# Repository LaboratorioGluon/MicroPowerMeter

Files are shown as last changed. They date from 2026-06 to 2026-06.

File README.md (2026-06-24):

# MicroPowerMeter

This repo contains the Hardware design of my version of a low current meter (from nanoamperes to milliamperes).

More Info [Blog Entry](https://en.laboratoriogluon.com/projects/micropowermeter/).

## Capabilities

- 4 kSps
- 3 Ranges: nA, uA and mA.
- Automatic range switching
- USB connection.
- Low Burden Voltage:
    - 10 uV/nA 
    - 10 uV/uA
    - 10 uV/mA

## Electrical characteristics

- TBD

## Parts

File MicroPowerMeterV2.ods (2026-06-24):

Reference | Qty | Value | PiceUd | Total price | DNP | Exclude from BOM | Footprint | Datasheet
C1,C3,C5,C6,C11,C23,C24,C50,C51,C53,C56 | 11 | 1u | 0.0022 | 0.0242 |  |  | Capacitor_SMD:C_0603_1608Metric
C2,C4,C52 | 3 | 100u | 0.06 | 0.18 |  |  | Capacitor_SMD:C_0603_1608Metric
C7,C42,C48 | 3 | 100n | 0.0022 | 0.0066 |  |  | Capacitor_SMD:C_0603_1608Metric_Pad1.08x0.95mm_HandSolder
C8 | 1 | 4u7 | 0.0022 | 0.0022 |  |  | Capacitor_SMD:C_0603_1608Metric_Pad1.08x0.95mm_HandSolder
C9,C10 | 2 | 10n | 0.0022 | 0.0044 |  |  | Capacitor_SMD:C_0603_1608Metric_Pad1.08x0.95mm_HandSolder
C12,C13,C47,C49 | 4 | 1uF | 0.0022 | 0.0088 |  |  | Capacitor_SMD:C_0603_1608Metric_Pad1.08x0.95mm_HandSolder
C14 | 1 | 220n | 0.0022 | 0.0022 |  |  | Capacitor_SMD:C_0603_1608Metric_Pad1.08x0.95mm_HandSolder
C15,C16,C19,C20,C25,C29,C30,C31,C34,C36,C39,C40,C41,C43,C44,C45,C46 | 17 | 100n | 0.0022 | 0.0374 |  |  | Capacitor_SMD:C_0603_1608Metric
C17,C18,C21,C22,C57,C58,C59,C60,C61,C62 | 10 | 22n | 0.0022 | 0.022 |  |  | Capacitor_SMD:C_0603_1608Metric
C26,C27 | 2 | 220n | 0.0022 | 0.0044 |  |  | Capacitor_SMD:C_0603_1608Metric
C28,C37,C38 | 3 | 100u | 0.06 | 0.18 |  |  | Capacitor_SMD:CP_Elec_6.3x5.4
C32,C33 | 2 | 10u | 0.0022 | 0.0044 |  |  | Capacitor_SMD:C_0603_1608Metric
C35 | 1 | 4u7 | 0.0022 | 0.0022 |  |  | Capacitor_SMD:C_0603_1608Metric
D1 | 1 | V_USB | 0.004 | 0.004 |  |  | LED_SMD:LED_0603_1608Metric
D2,D3 | 2 | V_3v3 | 0.004 | 0.008 |  |  | LED_SMD:LED_0603_1608Metric
D4 | 1 | 1N5819WS |  | 0 |  |  | Diode_SMD:D_SOD-323_HandSoldering | https://datasheet.lcsc.com/lcsc/2204281430_Guangdong-Hottech-1N5819WS_C191023.pdf
D5 | 1 | BAT54C | 0.02 | 0.02 |  |  | Package_TO_SOT_SMD:SOT-23 | http://www.diodes.com/_files/datasheets/ds11005.pdf
FB1,FB2 | 2 | 300R | 0.02 | 0.04 |  |  | Inductor_SMD:L_0603_1608Metric
J1 | 1 | USB_C_Receptacle_USB2.0_16P | 0.034 | 0.034 |  |  | USB_C_Receptacle_GCT_USB4105-xx-A_16P_TopMnt_Horizontal | https://www.usb.org/sites/default/files/documents/usb_type-c.zip
J2 | 1 | UART_DBG_CT |  | 0 |  |  | Connector_PinHeader_2.54mm:PinHeader_1x04_P2.54mm_Vertical
J3,J5 | 2 | SWD |  | 0 |  |  | Connector_PinHeader_2.54mm:PinHeader_1x04_P2.54mm_Vertical
J4 | 1 | OLED |  | 0 |  |  | GluonLib:OLED_0.96_footprint
J6 | 1 | BANANA_VIN | 0.5 | 0.5 |  |  | Connector_Wire:SolderWirePad_1x01_SMD_4x8mm
J7 | 1 | BANANA_DUT_P | 0.5 | 0.5 |  |  | Connector_Wire:SolderWirePad_1x01_SMD_4x8mm
J8,J9,J10,J11 | 4 | LED | 0.012 | 0.048 |  |  | Connector_PinHeader_2.54mm:PinHeader_1x02_P2.54mm_Vertical
J12 | 1 | SW | 0.05 | 0.05 |  |  | Connector_PinHeader_2.54mm:PinHeader_1x02_P2.54mm_Vertical
JP1 | 1 | 9VCurrent | 0.012 | 0.012 |  |  | Connector_PinHeader_2.54mm:PinHeader_1x02_P2.54mm_Vertical
Q1 | 1 | DMG2302UKQ | 0.149 | 0.149 |  |  | Package_TO_SOT_SMD:SOT-23
Q2 | 1 | DMG2302 | 0.149 | 0.149 |  |  | Package_TO_SOT_SMD:SOT-23
Q3,Q4 | 2 | IRLML2502 | 0.32 | 0.64 |  |  | Package_TO_SOT_SMD:SOT-23
R1,R2,R3,R4,R5,R6,R7,R15,R36 | 9 | 1k | 0.001 | 0.009 |  |  | Resistor_SMD:R_0603_1608Metric
R8,R9,R35,R39,R48,R54 | 6 | 0 | 0.001 | 0.006 |  |  | Resistor_SMD:R_0603_1608Metric
R10 | 1 | 10K 0.05% | 0.342 | 0.342 |  |  | Resistor_SMD:R_0603_1608Metric
R11,R12 | 2 | 100 | 0.001 | 0.002 |  |  | Resistor_SMD:R_0603_1608Metric
R13,R14,R37,R38,R41,R42 | 6 | 100k | 0.001 | 0.006 |  |  | Resistor_SMD:R_0603_1608Metric
R16 | 1 | 4k7 | 0.001 | 0.001 |  |  | Resistor_SMD:R_0603_1608Metric
R17 | 1 | 10R 0.05% | 0.362 | 0.362 |  |  | Resistor_SMD:R_0603_1608Metric
R18 | 1 | 0R01 0.1% | 0.609 | 0.609 |  |  | Resistor_SMD:R_Shunt_Ohmite_LVK12
R19,R20,R33,R34,R43,R44 | 6 | 270 | 0.001 | 0.006 |  |  | Resistor_SMD:R_0603_1608Metric
R21,R22,R27,R28 | 4 | 1K 0.05% | 0.342 | 1.368 |  |  | Resistor_SMD:R_0603_1608Metric
R23,R24,R29,R30 | 4 | 6K8 0.05% | 0.358 | 1.432 |  |  | Resistor_SMD:R_0603_1608Metric
R25,R26,R31,R32 | 4 | 2k2 0.05% | 0.358 | 1.432 |  |  | Resistor_SMD:R_0603_1608Metric
R40 | 1 | 200 | 0.001 | 0.001 |  |  | Resistor_SMD:R_0603_1608Metric
R45,R46 | 2 | 5k1 | 0.001 | 0.002 |  |  | Resistor_SMD:R_0603_1608Metric
R47 | 1 | 47 | 0.001 | 0.001 |  |  | Resistor_SMD:R_0603_1608Metric
R49,R50,R51,R52,R53 | 5 | 10 | 0.001 | 0.005 |  |  | Resistor_SMD:R_0603_1608Metric
TP2 | 1 | mA_TP |  | 0 |  |  | TestPoint:TestPoint_Pad_D1.0mm
TP3 | 1 | nAuA_TP |  | 0 |  |  | TestPoint:TestPoint_Pad_D1.0mm
TP4,TP5 | 2 | vsense_TP |  | 0 |  |  | TestPoint:TestPoint_Pad_D1.5mm
U1 | 1 | STM32C071RBTx | 1.58 | 1.58 |  |  | Package_QFP:LQFP-64_10x10mm_P0.5mm | https://www.st.com/resource/en/datasheet/stm32c071rb.pdf
U2,U11 | 2 | TLV773 | 0.043 | 0.086 |  |  | Package_TO_SOT_SMD:SOT-23-5 | https://www.ti.com/lit/ds/symlink/tlv773.pdf?ts=1765118738229
U3 | 1 | TEA1-0519HI | 2.86 | 2.86 |  |  | Converter_DCDC:Converter_DCDC_TRACO_TEA1-xxxxE_THT | https://www.tracopower.com/products/tea1e.pdf
U4 | 1 | ISO6742 | 1.75 | 1.75 |  |  | Package_SO:SOIC-16W_7.5x10.3mm_P1.27mm | https://www.ti.com/lit/ds/symlink/iso6742.pdf
U5 | 1 | STM32C011F4Px | 1.2 | 1.2 |  |  | Package_SO:TSSOP-20_4.4x6.5mm_P0.65mm | https://www.st.com/resource/en/datasheet/stm32c011f4.pdf
U6 | 1 | ADS131M03xPW | 2.4 | 2.4 |  |  | Package_SO:TSSOP-20_4.4x6.5mm_P0.65mm | https://www.ti.com/lit/ds/symlink/ads131m04.pdf
U7,U8,U9,U10 | 4 | MAX4239AUT | 1.5 | 6 |  |  | Package_TO_SOT_SMD:SOT-23-6 | http://datasheets.maximintegrated.com/en/ds/MAX4238-MAX4239.pdf
U12 | 1 | LM2665M6 |  | 0 |  |  | Package_TO_SOT_SMD:SOT-23-6 | https://www.ti.com/lit/ds/symlink/lm2665.pdf
U13 | 1 | OPA320DBV | 0.641 | 0.641 |  |  | Package_TO_SOT_SMD:SOT-23-5 | http://www.ti.com/lit/ds/symlink/lmv324.pdf
U14 | 1 | TPD2EUSB30A |  | 0 |  |  | Package_TO_SOT_SMD:Texas_DRT-3 | http://www.ti.com/lit/ds/symlink/tpd2eusb30a.pdf
U15 | 1 | XC6201P532PR-G | 0.321 | 0.321 |  |  | Package_TO_SOT_SMD:SOT-89-3 | https://product.torexsemi.com/system/files/series/xc6201.pdf
U16 | 1 | NCP163ASN500T1G | 0.225 | 0.225 |  |  | Package_TO_SOT_SMD:SOT-23-5 | https://www.onsemi.com/pdf/datasheet/ncp163-d.pdf
Y1 | 1 | ECS-2520MVLC-081.92-CN-TR | 1.25 | 1.25 |  |  | Oscillator:Oscillator_SMD_ECS_2520MV-xxx-xx-4Pin_2.5x2.0mm | https://www.ecsxtal.com/store/pdf/ECS-2520MV.pdf

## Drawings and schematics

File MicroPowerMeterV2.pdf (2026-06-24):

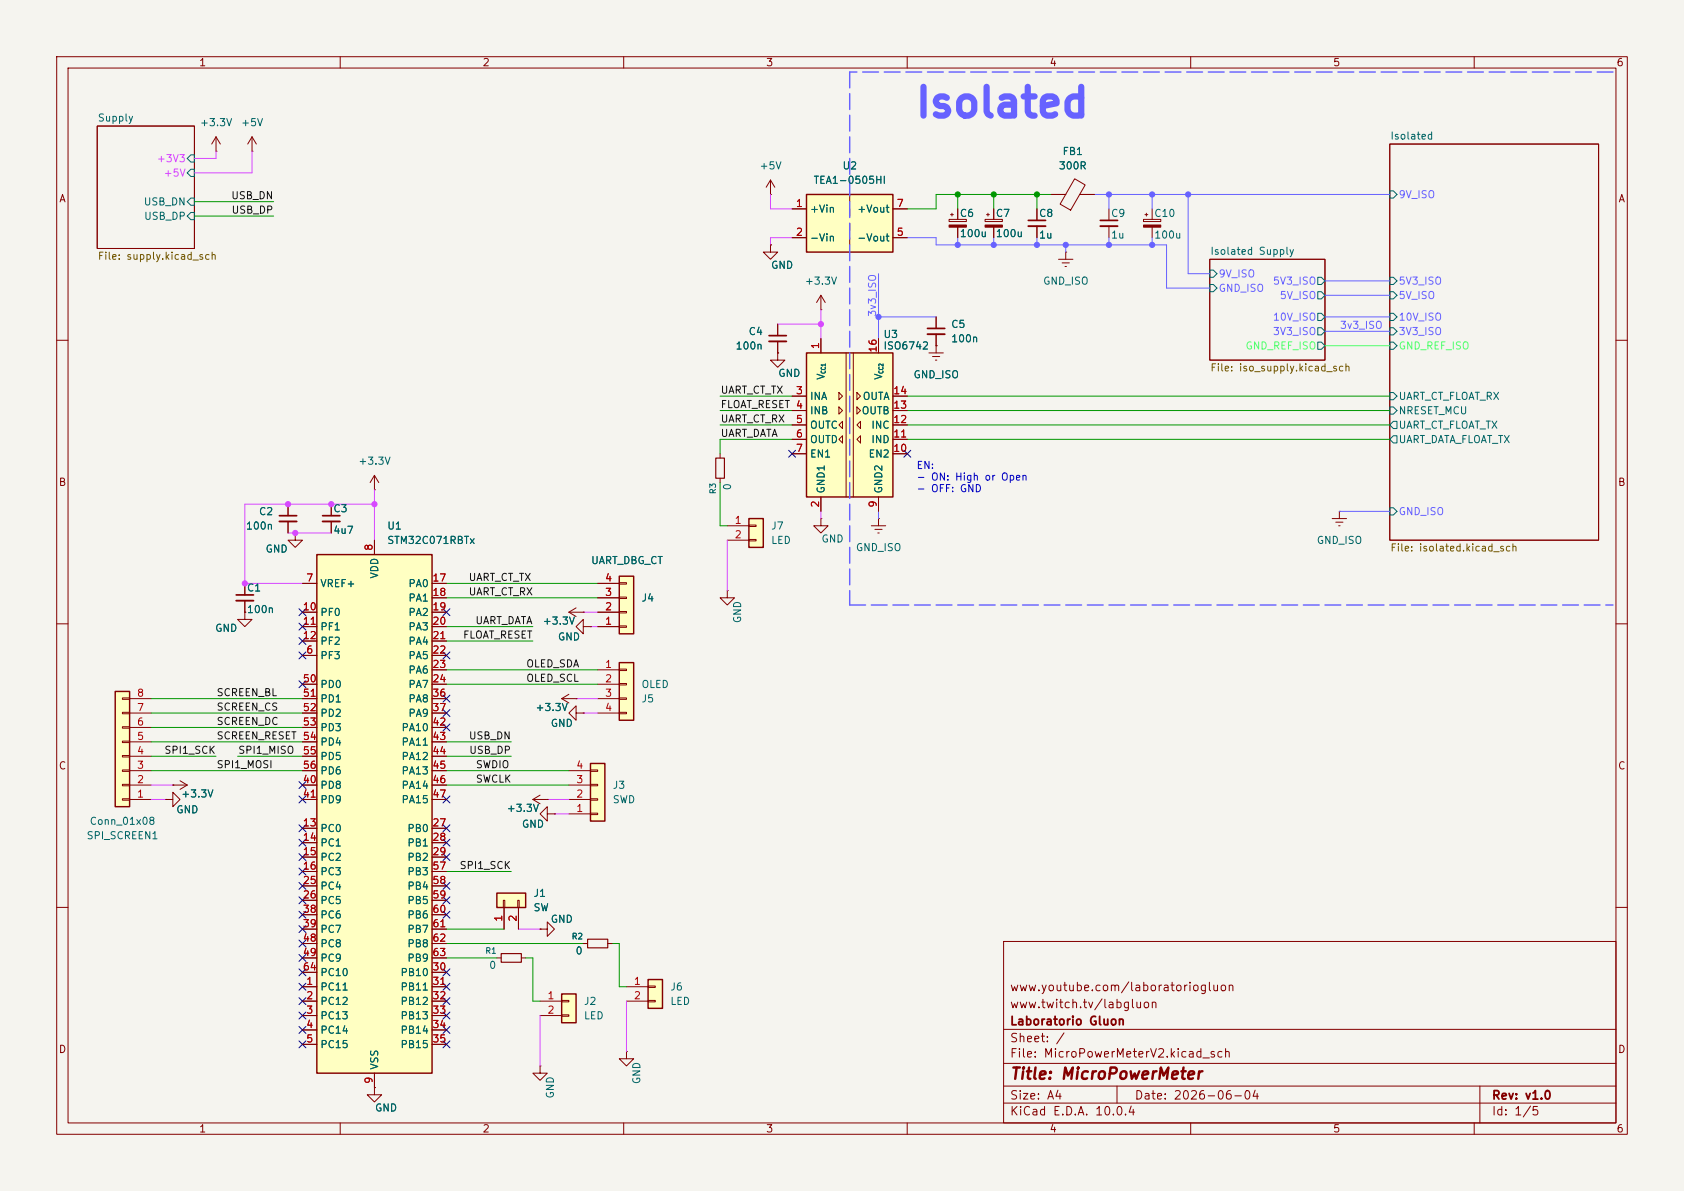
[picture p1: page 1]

EN: - ON: High or Open - OFF: GND Isolated

EN2 10 IND 11 INC 12 OUTB 13 OUTA 14

www.youtube.com/laboratoriogluon
www.twitch.tv/labgluon
Laboratorio Gluon
Sheet: /
File: MicroPowerMeterV2.kicad_sch
Title: MicroPowerMeter

Size: A4 | Rev: v1.0
KiCad E.D.A. 10.0.4 | Id: 1/5

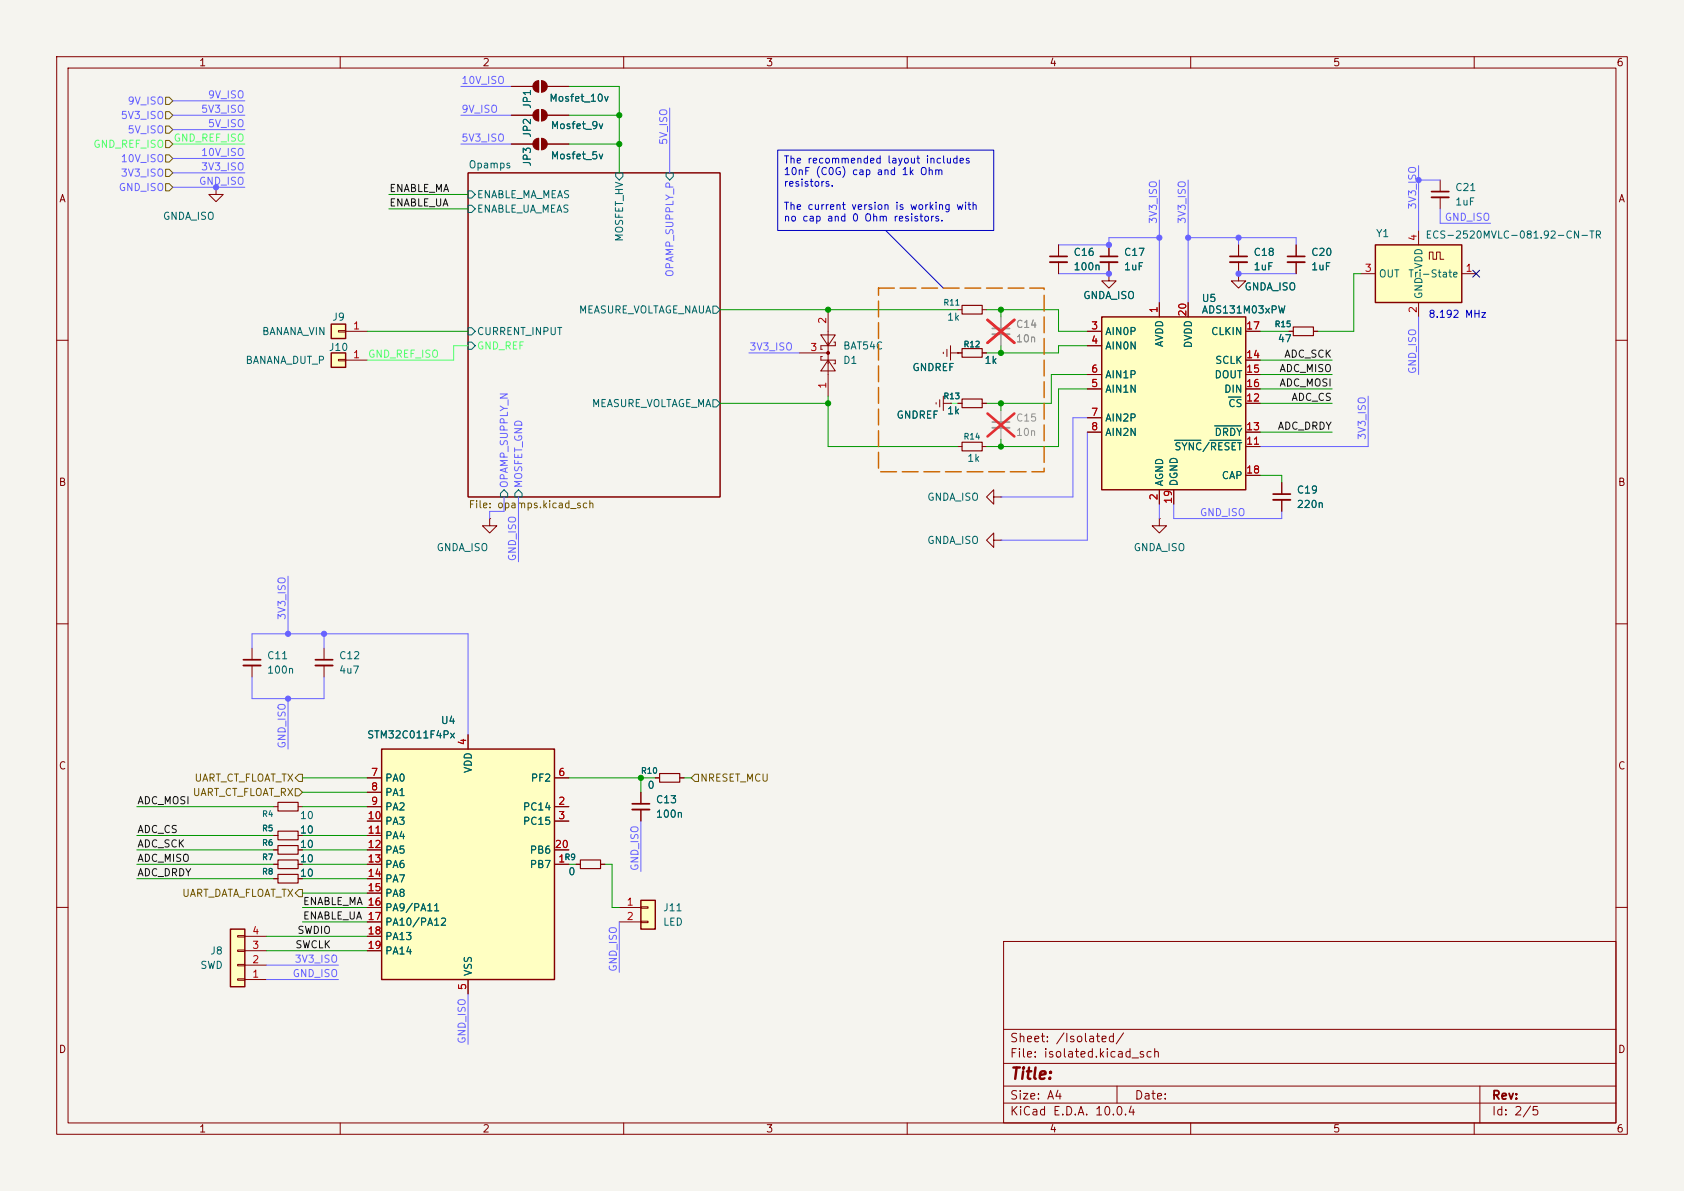
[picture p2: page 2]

The recommended layout includes 10nF (C0G) cap and 1k Ohm

resistors. The current version is working with

SYNC/RESET 11 CS 12 DRDY 13

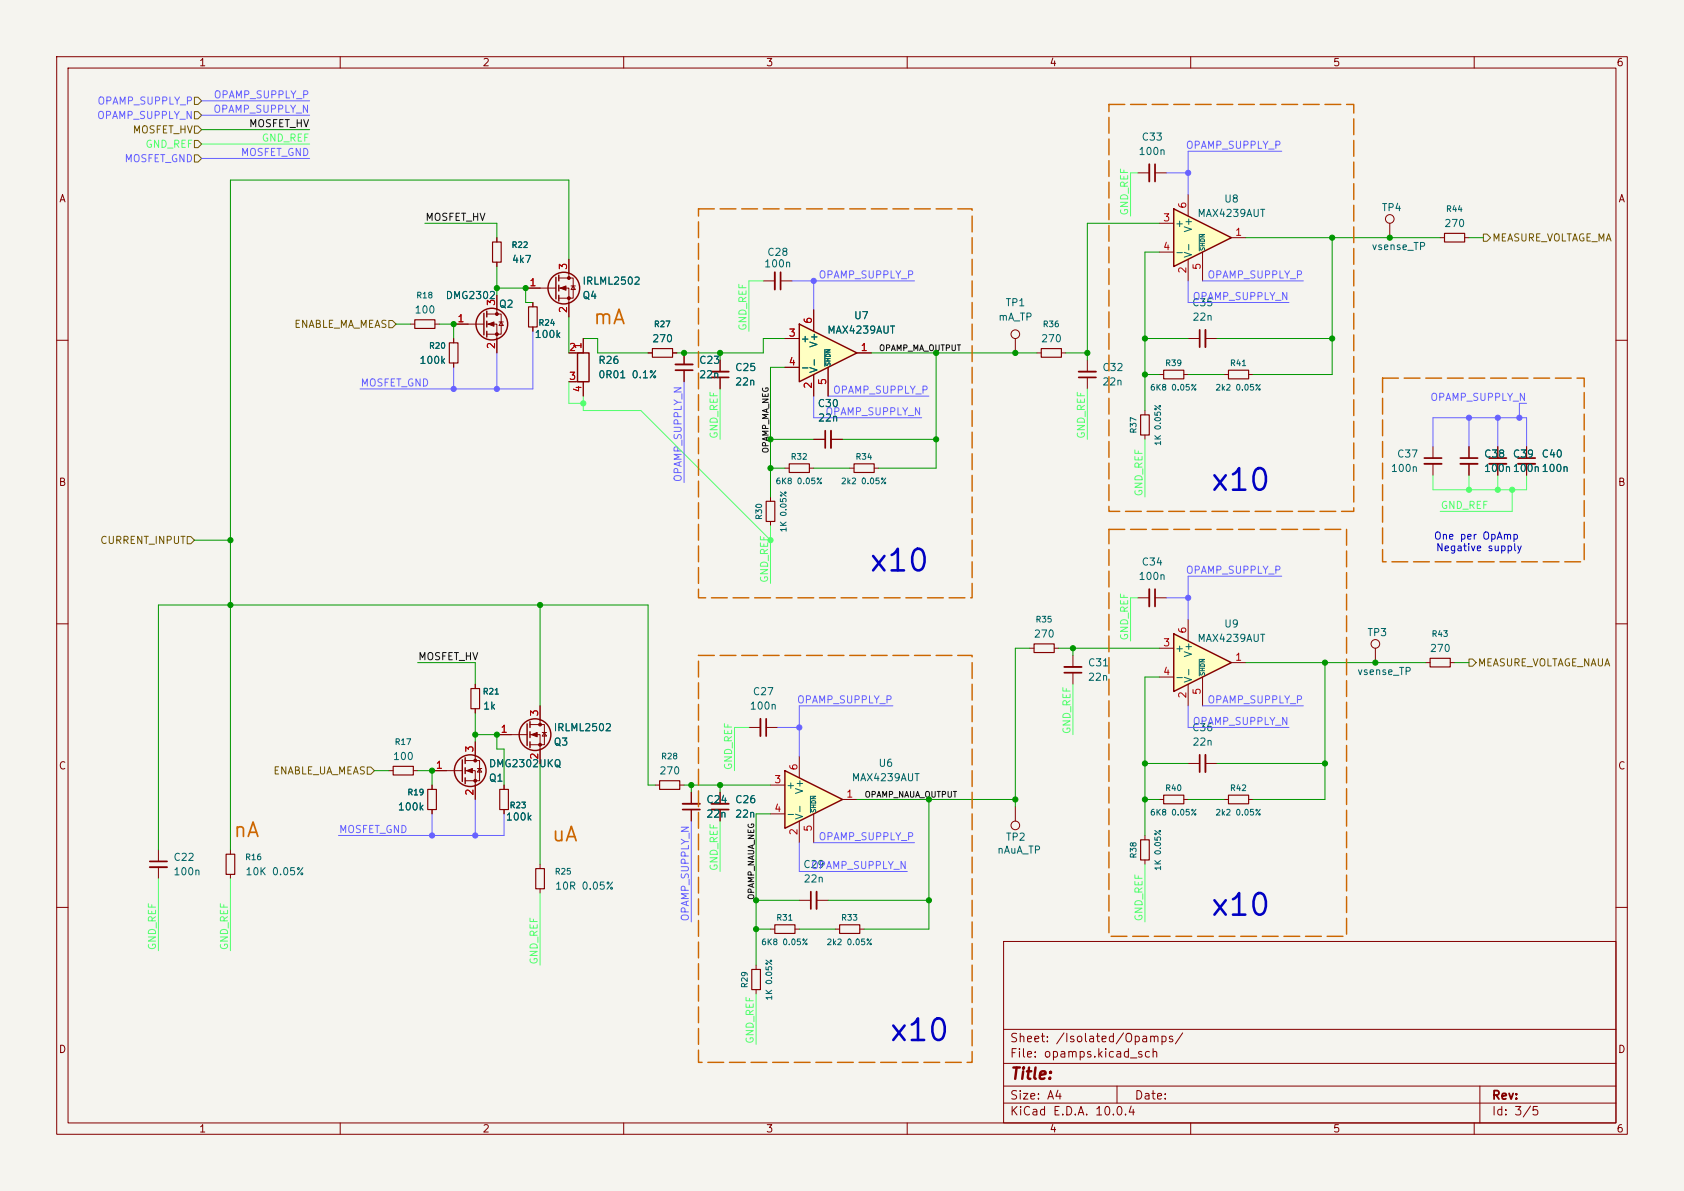
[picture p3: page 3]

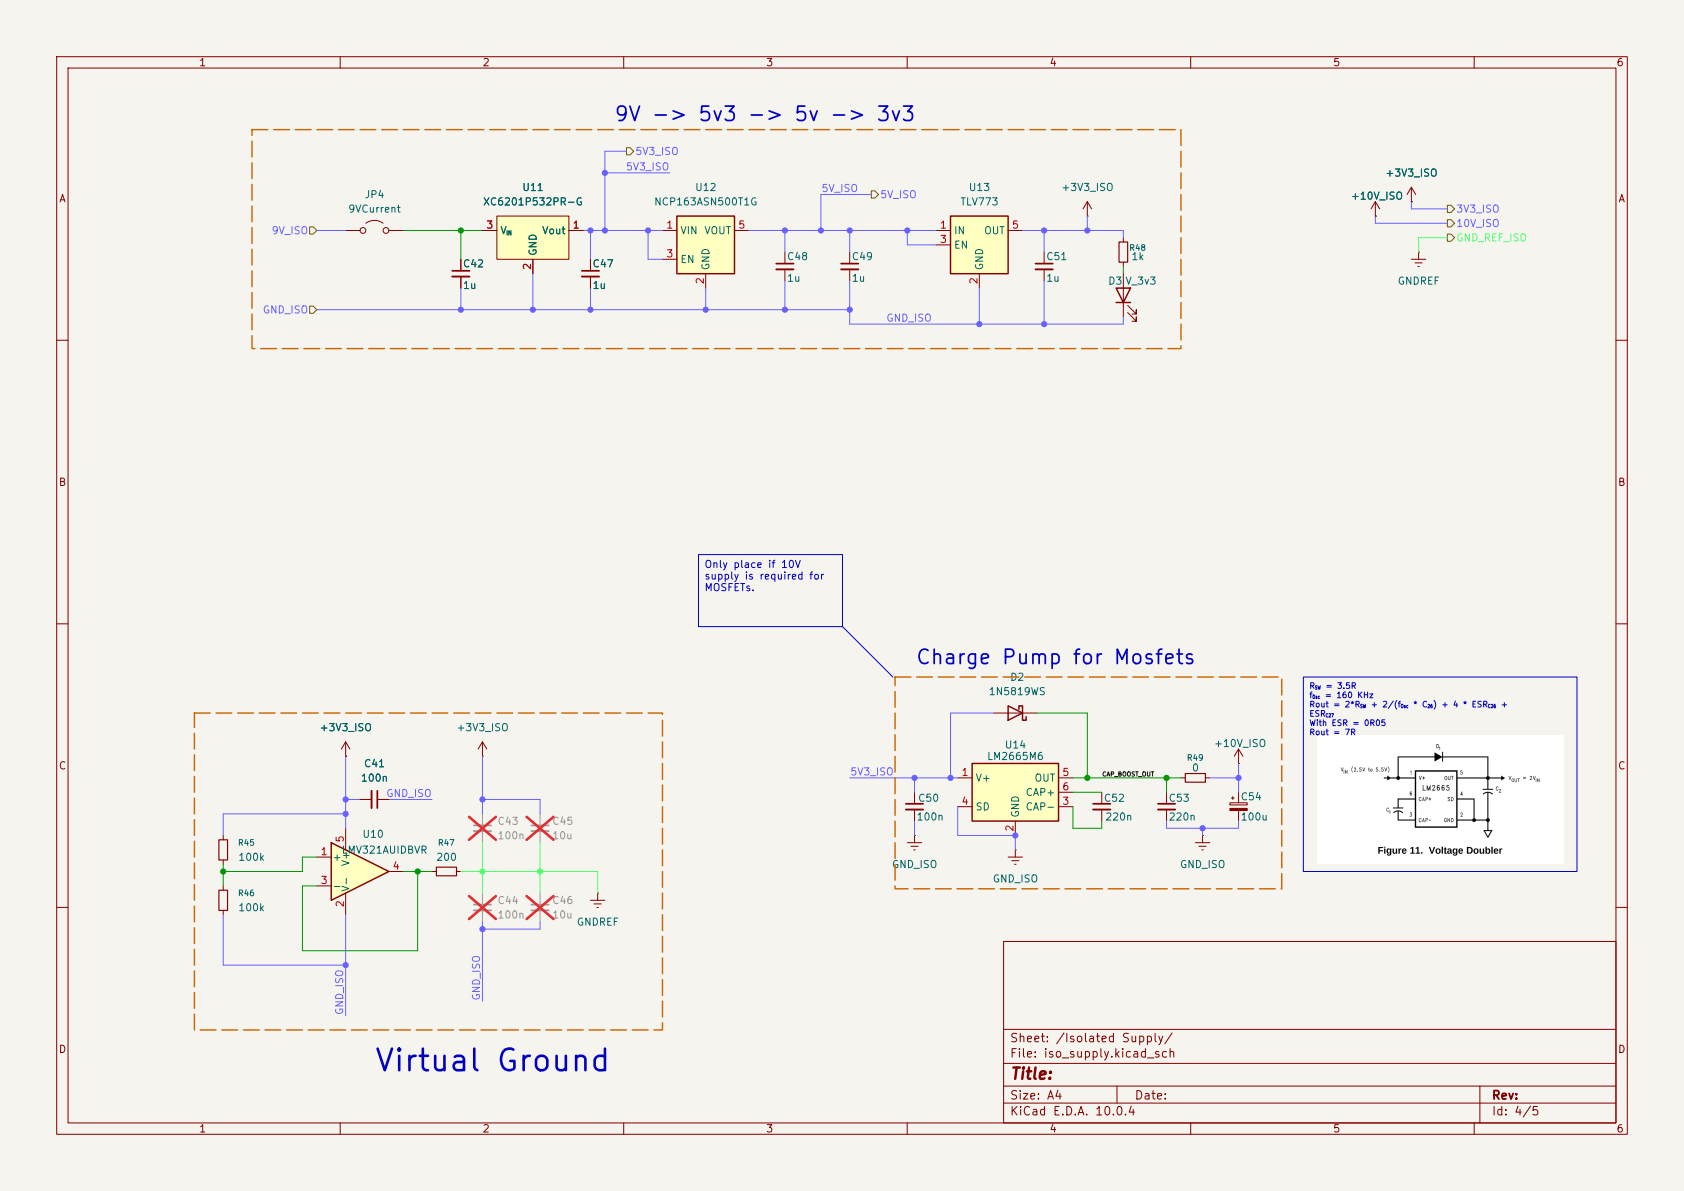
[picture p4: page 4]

ESRC27 With ESR = 0R05 Rout = 7R Charge Pump for Mosfets

fOsc = 160 KHz Rout = 2*RSW + 2/(fOsc * C26) + 4 * ESRC26 +

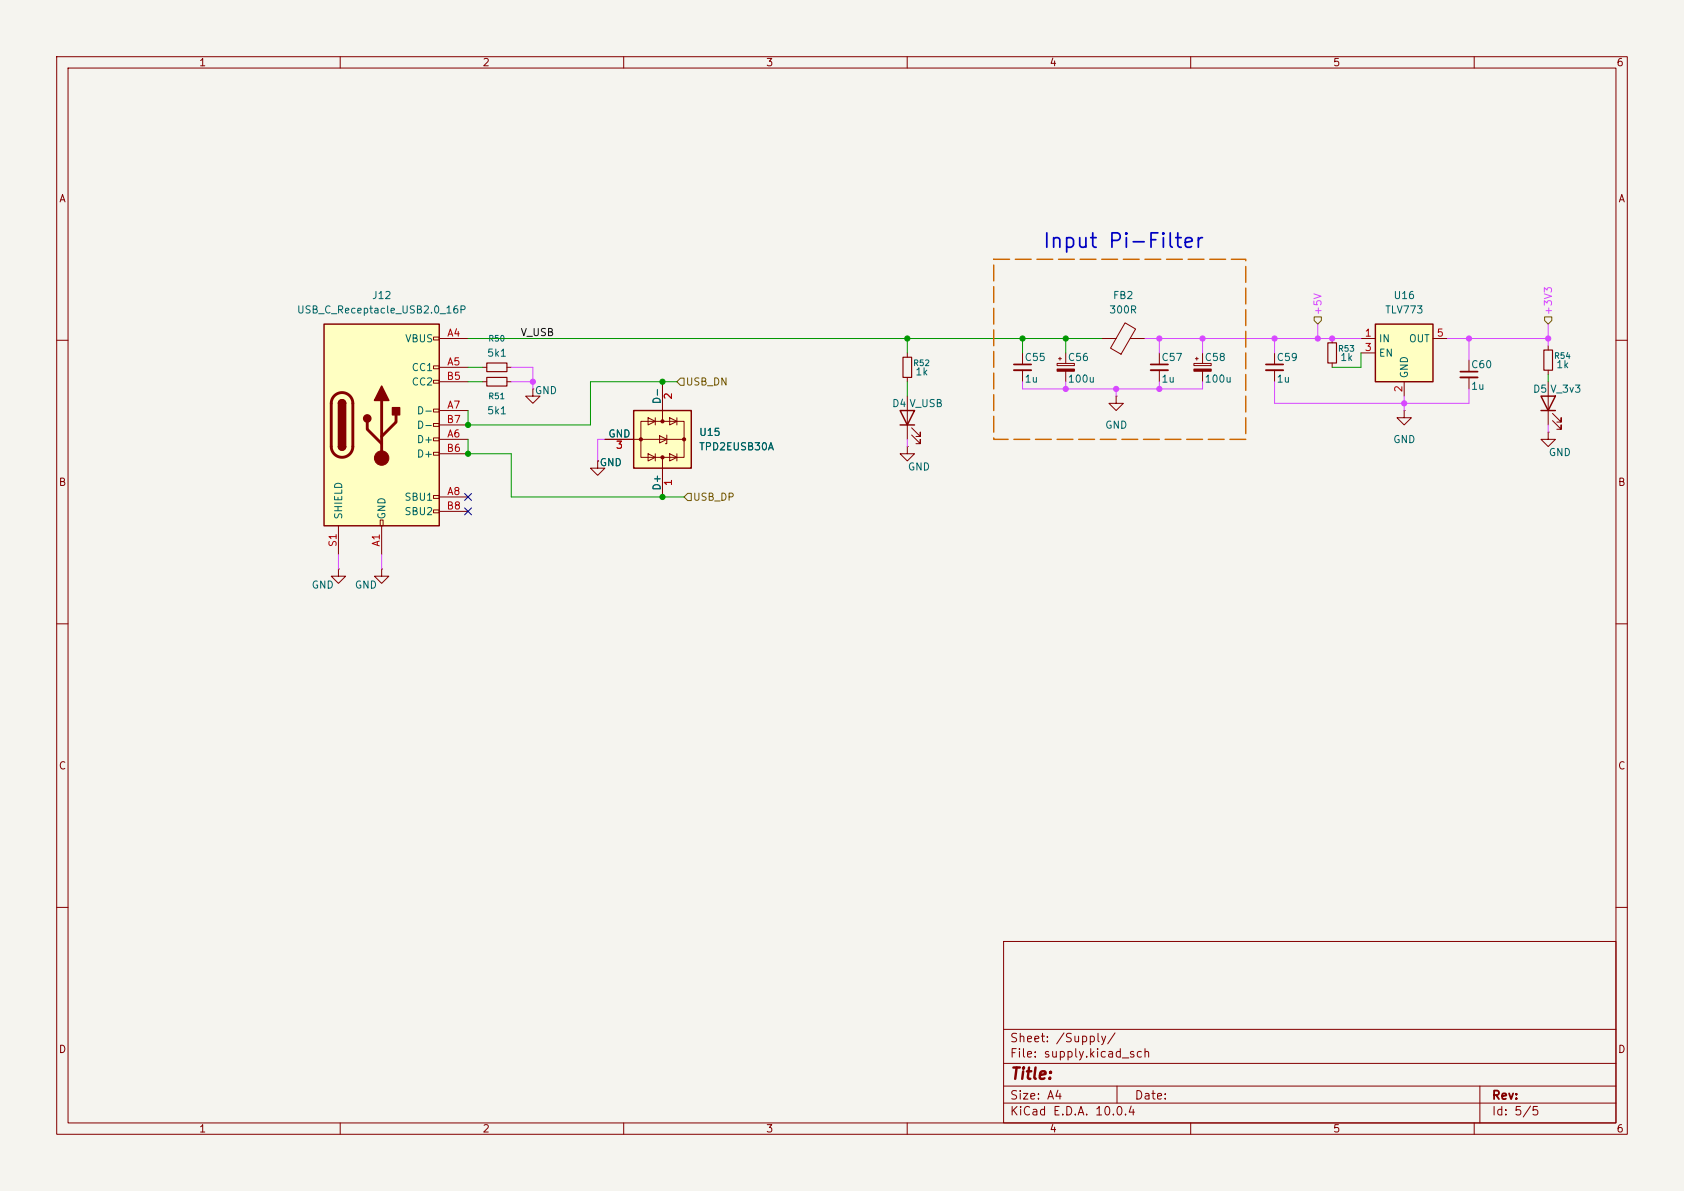
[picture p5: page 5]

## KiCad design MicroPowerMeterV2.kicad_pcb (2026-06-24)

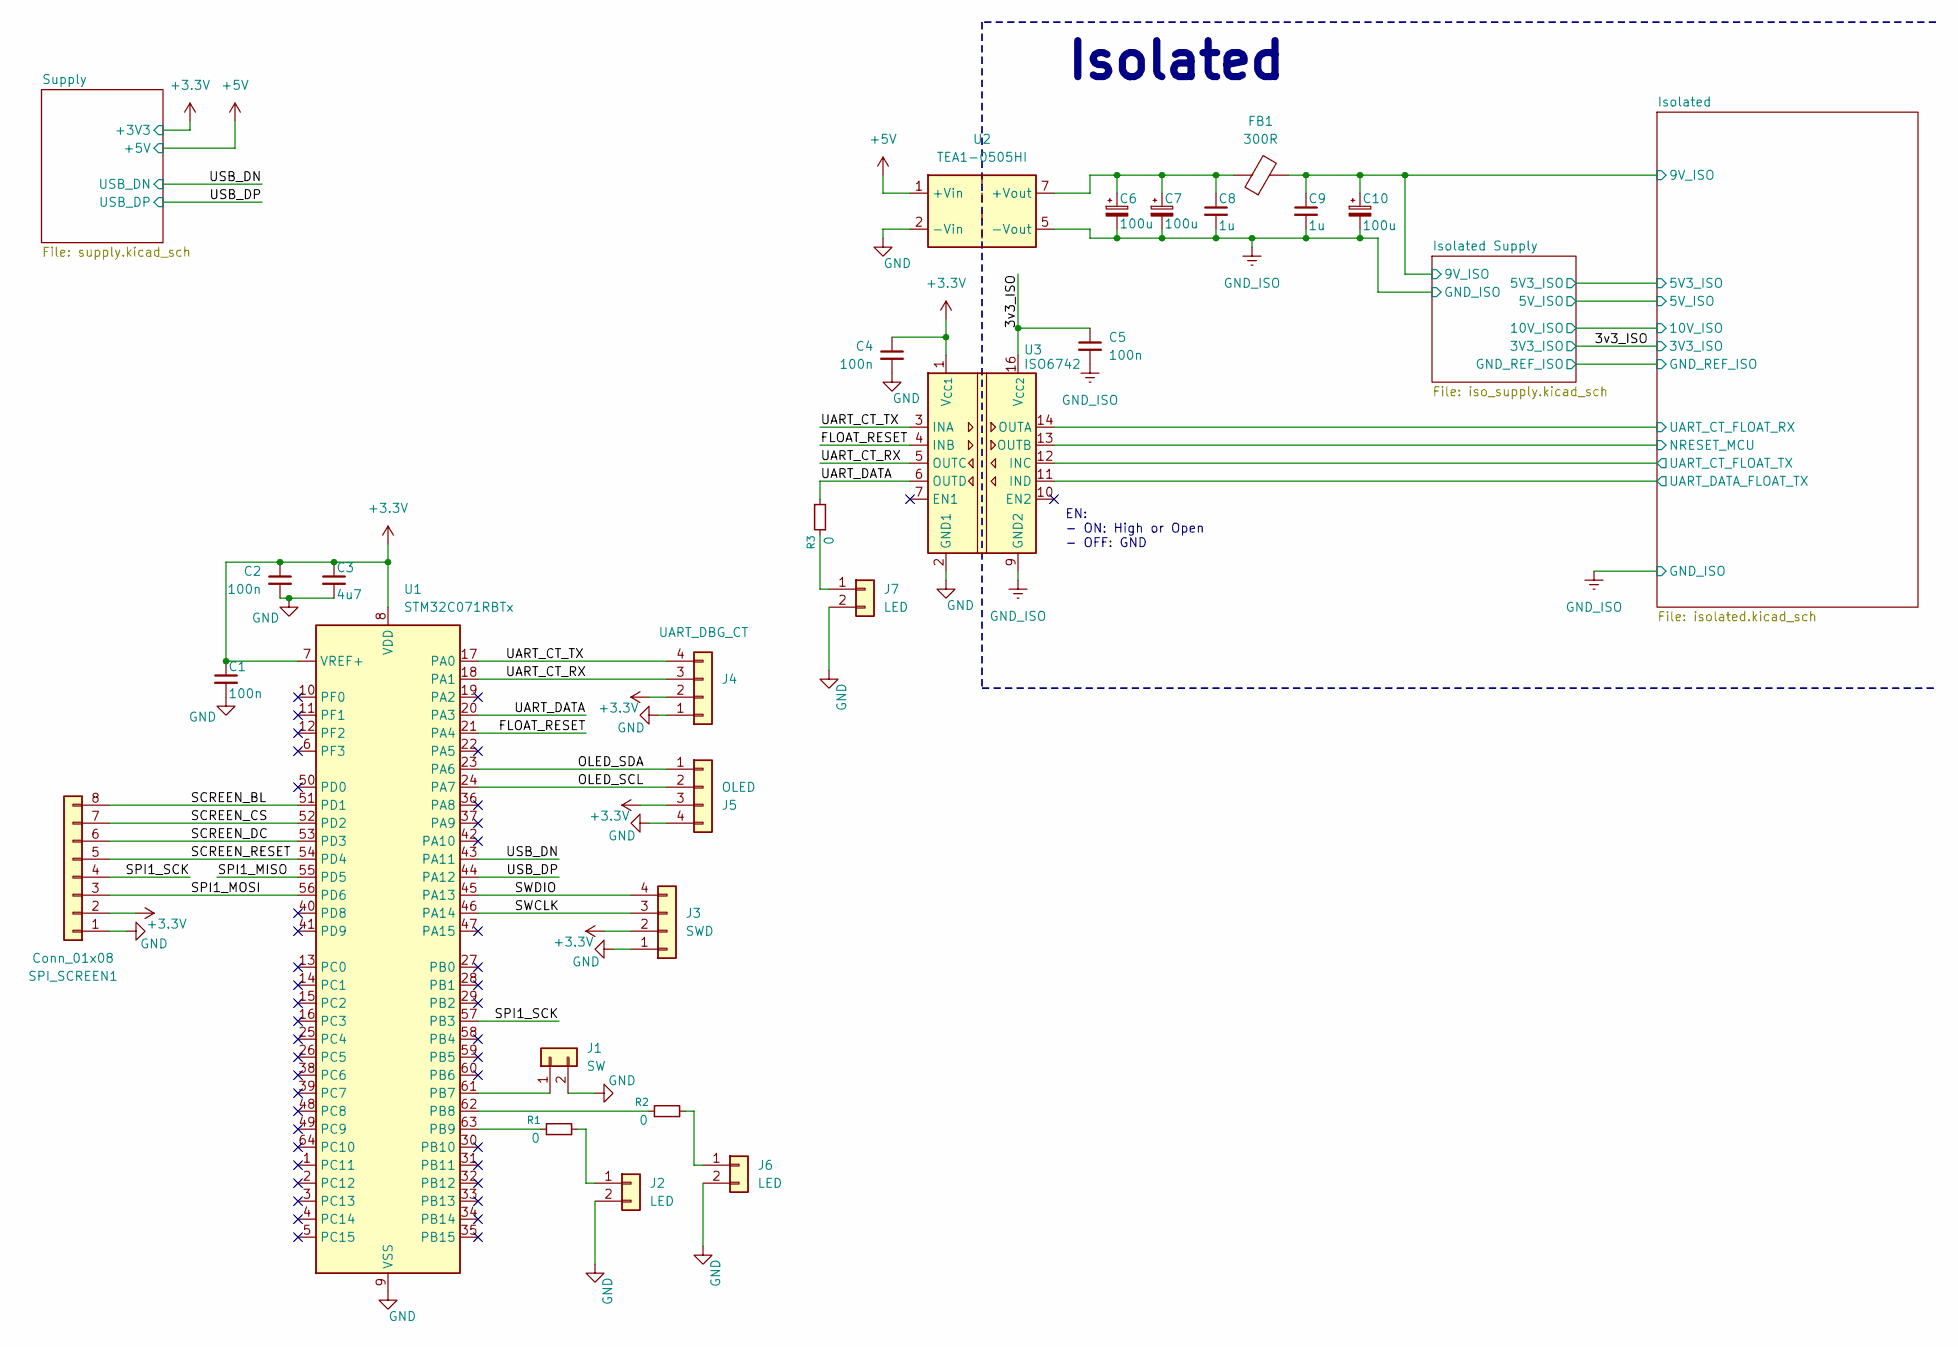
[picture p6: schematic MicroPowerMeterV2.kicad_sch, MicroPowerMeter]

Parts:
C1, C2, C4, C5: 100n; C_0603_1608Metric
C3: 4u7; C_0603_1608Metric
C6, C7: 100u; CP_Elec_6.3x5.4
C8, C9: 1u; C_0603_1608Metric
C10: 100u; C_0603_1608Metric
FB1: 300R; L_0603_1608Metric; PartNumber MMZ1608S301ATA00
J1: SW; PinHeader_1x02_P2.54mm_Vertical
J2, J6, J7: LED; PinHeader_1x02_P2.54mm_Vertical
J3: SWD; PinHeader_1x04_P2.54mm_Vertical
J4: UART_DBG_CT; PinHeader_1x04_P2.54mm_Vertical
J5: OLED; OLED_0.96_footprint
R1, R2, R3: 0; R_0603_1608Metric
SPI_SCREEN1: Conn_01x08; PinHeader_1x08_P2.54mm_Vertical
U1: STM32C071RBTx; LQFP-64_10x10mm_P0.5mm
U2: TEA1-0505HI; Converter_DCDC_TRACO_TEA1-xxxxHI_THT
U3: ISO6742; SOIC-16W_7.5x10.3mm_P1.27mm

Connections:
+3.3V: C1.1, C2.1, C3.1, C4.1, J3.2, J4.2, J5.3, SPI_SCREEN1.2, U1.7 (VREF+), U1.8 (VDD), U3.1 (V_{CC1}); also elsewhere on the board
+3V3_ISO: C5.1, U3.16 (V_{CC2}); also elsewhere on the board
+5V: U2.1 (+Vin); also elsewhere on the board
/FLOAT_RESET: U1.21 (PA4), U3.4 (INB)
/Isolated/9V_ISO: C9.1, C10.1, FB1.2; also elsewhere on the board
/Isolated/NRESET_MCU: U3.13 (OUTB); also elsewhere on the board
/Isolated/UART_CT_FLOAT_RX: U3.14 (OUTA); also elsewhere on the board
/Isolated/UART_CT_FLOAT_TX: U3.12 (INC); also elsewhere on the board
/Isolated/UART_DATA_FLOAT_TX: U3.11 (IND); also elsewhere on the board
/OLED_SCL: J5.2, U1.24 (PA7)
/OLED_SDA: J5.1, U1.23 (PA6)
/SCREEN_BL: SPI_SCREEN1.8, U1.51 (PD1)
/SCREEN_CS: SPI_SCREEN1.7, U1.52 (PD2)
/SCREEN_DC: SPI_SCREEN1.6, U1.53 (PD3)
/SCREEN_RESET: SPI_SCREEN1.5, U1.54 (PD4)
/SPI1_MISO: U1.55 (PD5)
/SPI1_MOSI: SPI_SCREEN1.3, U1.56 (PD6)
/SPI1_SCK: SPI_SCREEN1.4, U1.57 (PB3)
/SWCLK: J3.3, U1.46 (PA14)
/SWDIO: J3.4, U1.45 (PA13)
/UART_CT_RX: J4.3, U1.18 (PA1), U3.5 (OUTC)
/UART_CT_TX: J4.4, U1.17 (PA0), U3.3 (INA)
/UART_DATA: R3.2, U1.20 (PA3), U3.6 (OUTD)
/USB_DN: U1.43 (PA11); also elsewhere on the board
/USB_DP: U1.44 (PA12); also elsewhere on the board
GND: C1.2, C2.2, C3.2, C4.2, J1.2, J2.2, J3.1, J4.1, J5.4, J6.2, J7.2, SPI_SCREEN1.1, U1.9 (VSS), U2.2 (-Vin), U3.2 (GND1), U3.8 (GND1); also elsewhere on the board
GND_ISO: C5.2, C6.2, C7.2, C8.2, C9.2, C10.2, U2.5 (-Vout), U3.9 (GND2), U3.15 (GND2); also elsewhere on the board
unnamed: J1.1, U1.61 (PB7)
unnamed: J2.1, R1.2
unnamed: J6.1, R2.2
unnamed: J7.1, R3.1
unnamed: R2.1, U1.62 (PB8)
unnamed: R1.1, U1.63 (PB9)
unnamed: C6.1, C7.1, C8.1, FB1.1, U2.7 (+Vout)

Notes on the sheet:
Isolated
EN: - ON: High or Open - OFF: GND

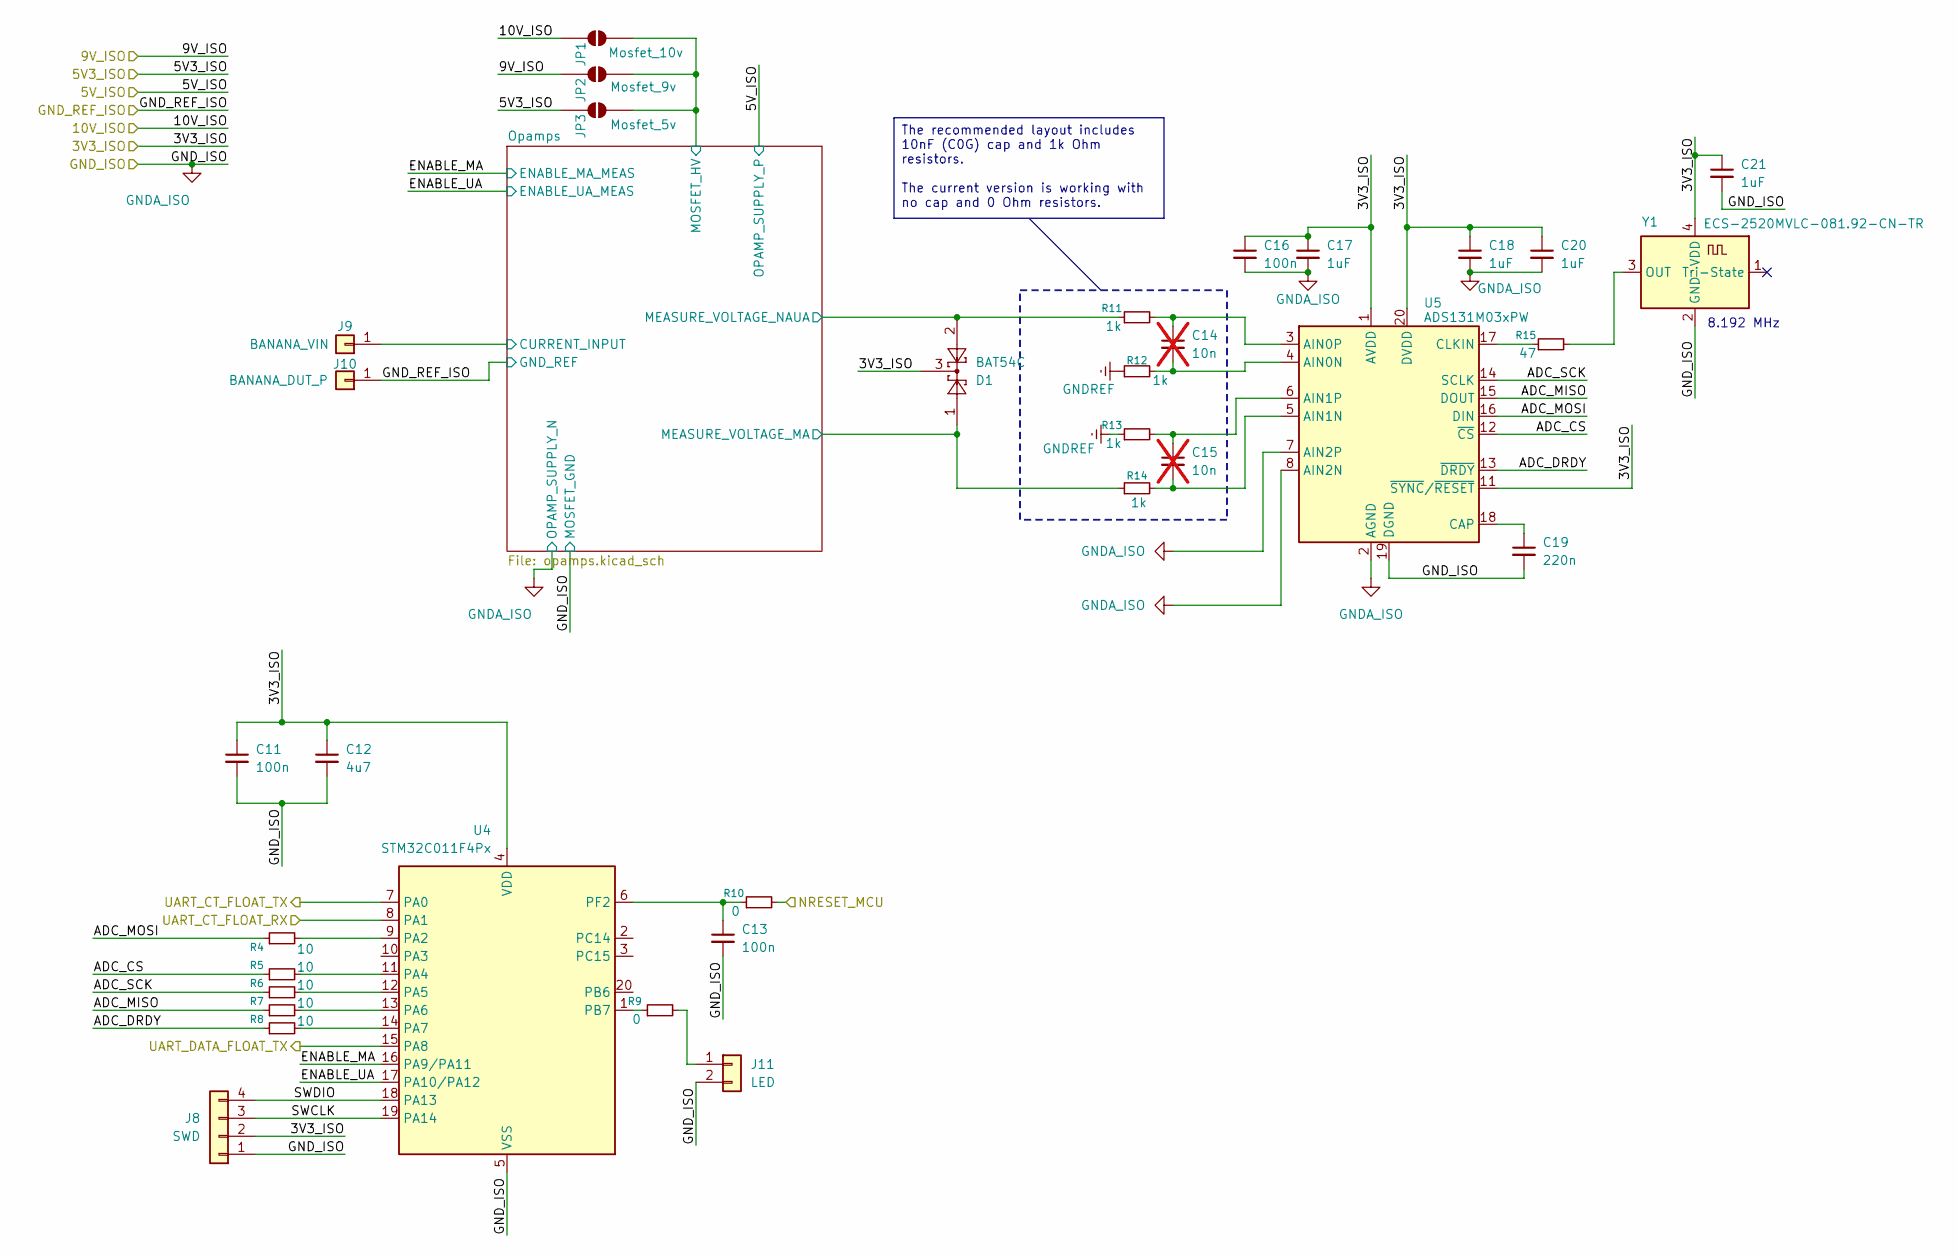
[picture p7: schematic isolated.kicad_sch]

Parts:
C11, C13, C16: 100n; C_0603_1608Metric_Pad1.08x0.95mm_HandSolder
C12: 4u7; C_0603_1608Metric_Pad1.08x0.95mm_HandSolder
C14, C15: 10n; C_0603_1608Metric_Pad1.08x0.95mm_HandSolder; not fitted
C17, C18, C20, C21: 1uF; C_0603_1608Metric_Pad1.08x0.95mm_HandSolder
C19: 220n; C_0603_1608Metric_Pad1.08x0.95mm_HandSolder
D1: BAT54C; SOT-23
J8: SWD; PinHeader_1x04_P2.54mm_Vertical
J9: BANANA_VIN; SolderWirePad_1x01_SMD_4x8mm
J10: BANANA_DUT_P; SolderWirePad_1x01_SMD_4x8mm
J11: LED; PinHeader_1x02_P2.54mm_Vertical
JP1: Mosfet_10v; SolderJumper-2_P1.3mm_Open_RoundedPad1.0x1.5mm
JP2: Mosfet_9v; SolderJumper-2_P1.3mm_Open_RoundedPad1.0x1.5mm
JP3: Mosfet_5v; SolderJumper-2_P1.3mm_Open_RoundedPad1.0x1.5mm
R4, R5, R6, R7, R8: 10; R_0603_1608Metric
R9, R10: 0; R_0603_1608Metric
R11, R12, R13, R14: 1k; R_0603_1608Metric
R15: 47; R_0603_1608Metric
U4: STM32C011F4Px; TSSOP-20_4.4x6.5mm_P0.65mm
U5: ADS131M03xPW; TSSOP-20_4.4x6.5mm_P0.65mm
Y1: ECS-2520MVLC-081.92-CN-TR; Oscillator_SMD_ECS_2520MV-xxx-xx-4Pin_2.5x2.0mm

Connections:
+3V3_ISO: C11.1, C12.1, C16.1, C17.1, C18.1, C20.1, C21.1, D1.3, J8.2, U4.4 (VDD), U5.1 (AVDD), U5.11 (~SYNC/~RESET), U5.20 (DVDD), Y1.4 (VDD); also elsewhere on the board
+10V_ISO: JP1.2 (B); also elsewhere on the board
/Isolated Supply/5V3_ISO: JP3.2 (B); also elsewhere on the board
/Isolated/9V_ISO: JP2.2 (B); also elsewhere on the board
/Isolated/ADC_CS: R5.1, U5.12 (~CS)
/Isolated/ADC_DRDY: R8.1, U5.13 (~DRDY)
/Isolated/ADC_MISO: R7.1, U5.15 (DOUT)
/Isolated/ADC_MOSI: R4.1, U5.16 (DIN)
/Isolated/ADC_SCK: R6.1, U5.14 (SCLK)
/Isolated/ENABLE_MA: U4.16 (PA9/PA11); also elsewhere on the board
/Isolated/ENABLE_UA: U4.17 (PA10/PA12); also elsewhere on the board
/Isolated/NRESET_MCU: R10.2; also elsewhere on the board
/Isolated/Opamps/CURRENT_INPUT: J9.1 (Pin_1_1); also elsewhere on the board
/Isolated/Opamps/MEASURE_VOLTAGE_MA: D1.1, R14.1; also elsewhere on the board
/Isolated/Opamps/MEASURE_VOLTAGE_NAUA: D1.2, R11.1; also elsewhere on the board
/Isolated/Opamps/MOSFET_HV: JP1.1 (A), JP2.1 (A), JP3.1 (A); also elsewhere on the board
/Isolated/SWCLK: J8.3, U4.19 (PA14)
/Isolated/SWDIO: J8.4, U4.18 (PA13)
/Isolated/UART_CT_FLOAT_RX: U4.8 (PA1); also elsewhere on the board
/Isolated/UART_CT_FLOAT_TX: U4.7 (PA0); also elsewhere on the board
/Isolated/UART_DATA_FLOAT_TX: U4.15 (PA8); also elsewhere on the board
GNDREF: J10.1 (Pin_1_1), R12.1, R13.1; also elsewhere on the board
GND_ISO: C11.2, C12.2, C13.2, C16.2, C17.2, C18.2, C19.2, C20.2, C21.2, J8.1, J11.2, U4.5 (VSS), U5.2 (AGND), U5.7 (AIN2P), U5.8 (AIN2N), U5.19 (DGND), Y1.2 (GND); also elsewhere on the board
unnamed: J11.1, R9.2
unnamed: R4.2, U4.9 (PA2)
unnamed: R5.2, U4.11 (PA4)
unnamed: R6.2, U4.12 (PA5)
unnamed: R7.2, U4.13 (PA6)
unnamed: R8.2, U4.14 (PA7)
unnamed: R9.1, U4.1 (PB7)
unnamed: C13.1, R10.1, U4.6 (PF2)
unnamed: C14.2, R12.2, U5.4 (AIN0N)
unnamed: C14.1, R11.2, U5.3 (AIN0P)
unnamed: C15.2, R14.2, U5.5 (AIN1N)
unnamed: C15.1, R13.2, U5.6 (AIN1P)
unnamed: C19.1, U5.18 (CAP)
unnamed: R15.1, U5.17 (CLKIN)
unnamed: R15.2, Y1.3 (OUT)

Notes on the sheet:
8.192 MHz
The recommended layout includes 10nF (C0G) cap and 1k Ohm resistors. The current version is working with no cap and 0 Ohm resistors.

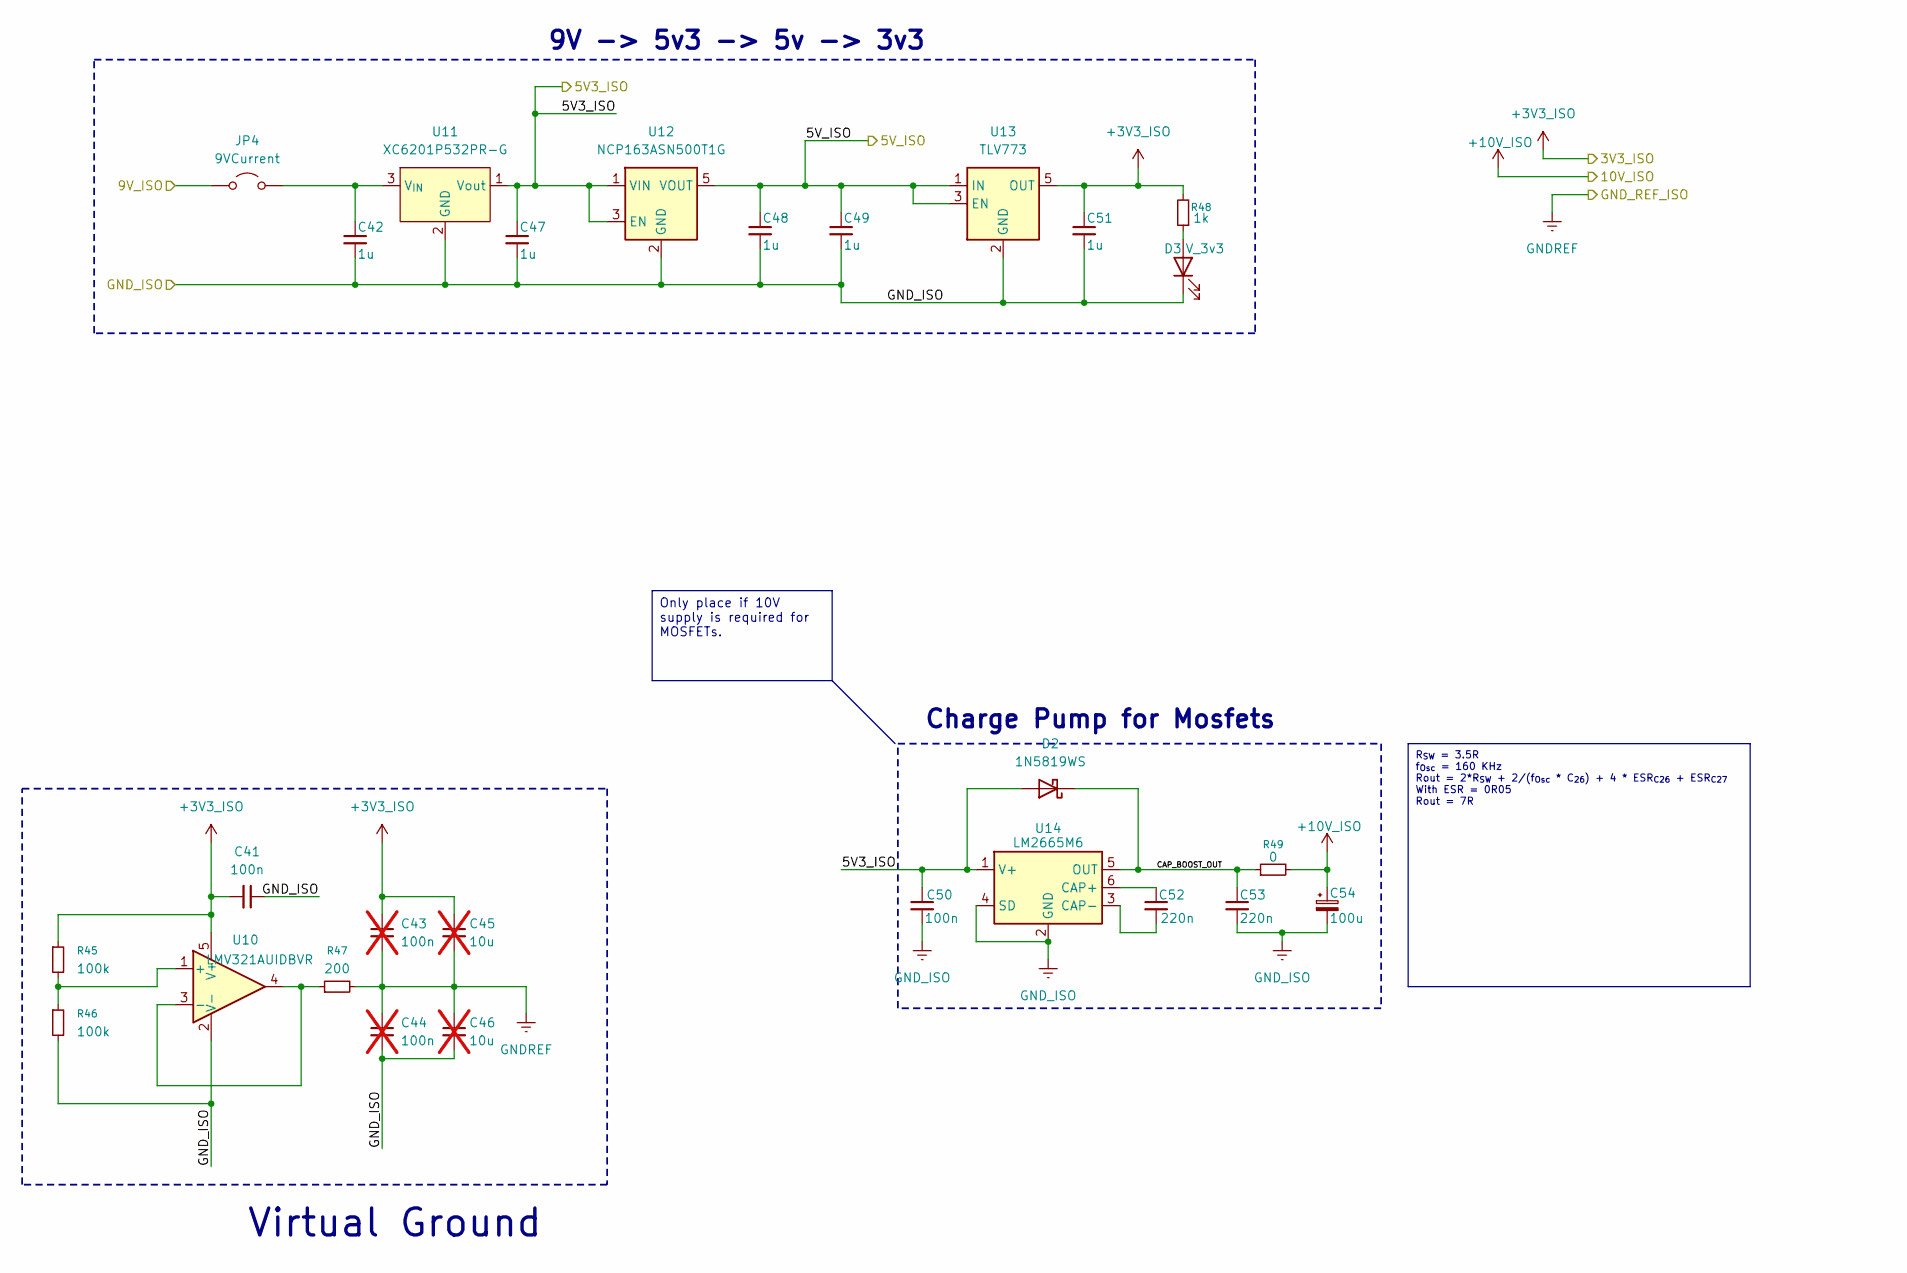
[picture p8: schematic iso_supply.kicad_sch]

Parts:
C41, C50: 100n; C_0603_1608Metric
C42, C47, C48, C49, C51: 1u; C_0603_1608Metric
C43, C44: 100n; C_0603_1608Metric; not fitted
C45, C46: 10u; C_0603_1608Metric; not fitted
C52, C53: 220n; C_0603_1608Metric
C54: 100u; CP_Elec_6.3x5.4
D2: 1N5819WS; D_SOD-323_HandSoldering
D3: V_3v3; LED_0603_1608Metric
JP4: 9VCurrent; PinHeader_1x02_P2.54mm_Vertical
R45, R46: 100k; R_0603_1608Metric
R47: 200; R_0603_1608Metric
R48: 1k; R_0603_1608Metric
R49: 0; R_0603_1608Metric
U10: LMV321AUIDBVR; SOT-23-5
U11: XC6201P532PR-G; SOT-89-3
U12: NCP163ASN500T1G; SOT-23-5
U13: TLV773; SOT-23-5
U14: LM2665M6; SOT-23-6; PartNumber LM2665M6X/NOPB

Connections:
+3V3_ISO: C41.2, C43.1, C45.1, C51.1, R45.1, R48.2, U10.5 (V+), U13.5 (OUT); also elsewhere on the board
+10V_ISO: C54.1, R49.2; also elsewhere on the board
/Isolated Supply/5V3_ISO: C47.1, C50.1, D2.2 (A), U11.1 (Vout), U12.1 (VIN), U12.3 (EN), U14.1 (V+); also elsewhere on the board
/Isolated Supply/5V_ISO: C48.1, C49.1, U12.5 (VOUT), U13.1 (IN), U13.3 (EN); also elsewhere on the board
/Isolated Supply/CAP_BOOST_OUT: C53.1, D2.1 (K), R49.1, U14.5 (OUT)
/Isolated/9V_ISO: JP4.1 (A); also elsewhere on the board
GNDREF: C43.2, C44.1, C45.2, C46.1, R47.2; also elsewhere on the board
GND_ISO: C41.1, C42.2, C44.2, C46.2, C47.2, C48.2, C49.2, C50.2, C51.2, C53.2, C54.2, D3.1 (K), R46.2, U10.2 (V-), U11.2 (GND), U12.2 (GND), U13.2 (GND), U13.4 (GND), U14.2 (GND), U14.4 (SD); also elsewhere on the board
unnamed: D3.2 (A), R48.1
unnamed: C42.1, JP4.2 (B), U11.3 (V_{IN})
unnamed: R45.2, R46.1, U10.1 (+)
unnamed: R47.1, U10.3 (-), U10.4
unnamed: C52.1, U14.6 (CAP+)
unnamed: C52.2, U14.3 (CAP-)

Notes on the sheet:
9V -> 5v3 -> 5v -> 3v3
Virtual Ground
Charge Pump for Mosfets
R_{SW} = 3.5R f_{Osc} = 160 KHz Rout = 2*R_{SW} + 2/(f_{Osc} * C_{26}) + 4 * ESR_{C26} + ESR_{C27} With ESR = 0R05 Rout = 7R
Only place if 10V supply is required for MOSFETs.

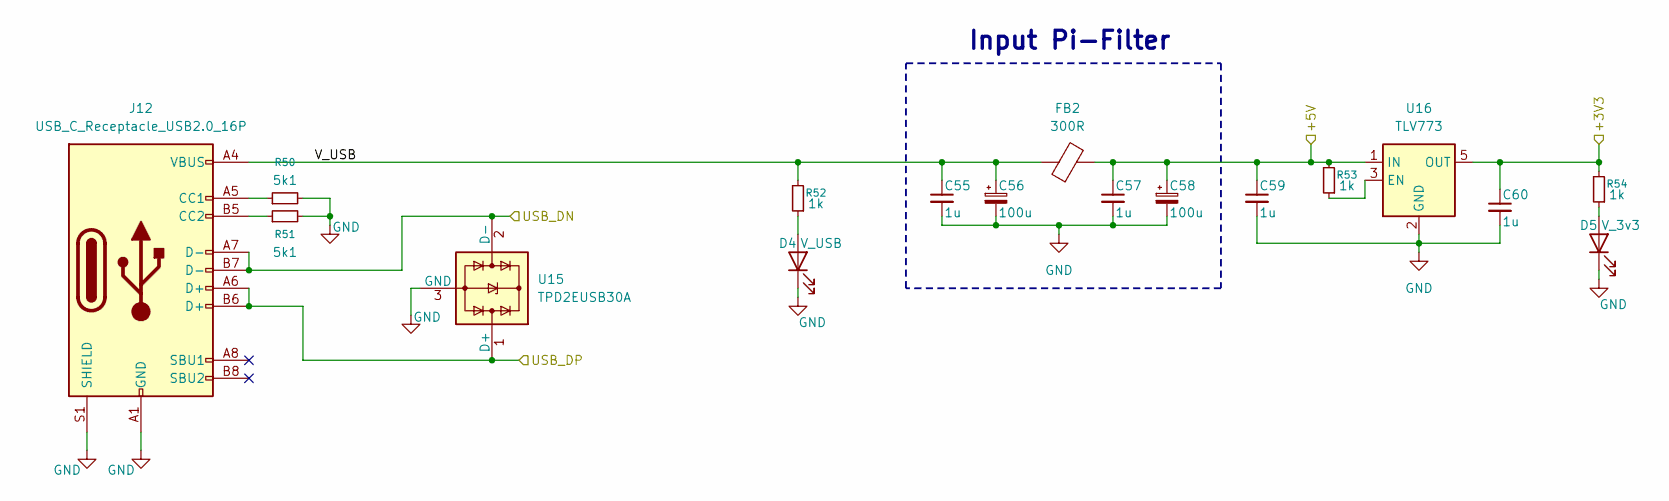
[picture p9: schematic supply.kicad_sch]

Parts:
C55, C57, C59, C60: 1u; C_0603_1608Metric
C56, C58: 100u; C_0603_1608Metric
D4: V_USB; LED_0603_1608Metric
D5: V_3v3; LED_0603_1608Metric
FB2: 300R; L_0603_1608Metric; PartNumber MMZ1608S301ATA00
J12: USB_C_Receptacle_USB2.0_16P; USB_C_Receptacle_GCT_USB4105-xx-A_16P_TopMnt_Horizontal
R50, R51: 5k1; R_0603_1608Metric
R52, R53, R54: 1k; R_0603_1608Metric
U15: TPD2EUSB30A; Texas_DRT-3
U16: TLV773; SOT-23-5

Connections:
+3.3V: C60.1, R54.2, U16.5 (OUT); also elsewhere on the board
+5V: C57.1, C58.1, C59.1, FB2.2, R53.2, U16.1 (IN); also elsewhere on the board
/Supply/V_USB: C55.1, C56.1, FB2.1, J12.A4 (VBUS), J12.A9 (VBUS), J12.B4 (VBUS), J12.B9 (VBUS), R52.2
/USB_DN: J12.A7 (D-), J12.B7 (D-), U15.2 (D-); also elsewhere on the board
/USB_DP: J12.A6 (D+), J12.B6 (D+), U15.1 (D+); also elsewhere on the board
GND: C55.2, C56.2, C57.2, C58.2, C59.2, C60.2, D4.1 (K), D5.1 (K), J12.A1 (GND), J12.A12 (GND), J12.B1 (GND), J12.B12 (GND), J12.S1 (SHIELD), R50.2, R51.2, U15.3 (GND), U16.2 (GND), U16.4 (GND); also elsewhere on the board
unnamed: D4.2 (A), R52.1
unnamed: D5.2 (A), R54.1
unnamed: J12.A5 (CC1), R50.1
unnamed: J12.B5 (CC2), R51.1
unnamed: R53.1, U16.3 (EN)

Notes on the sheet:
Input Pi-Filter

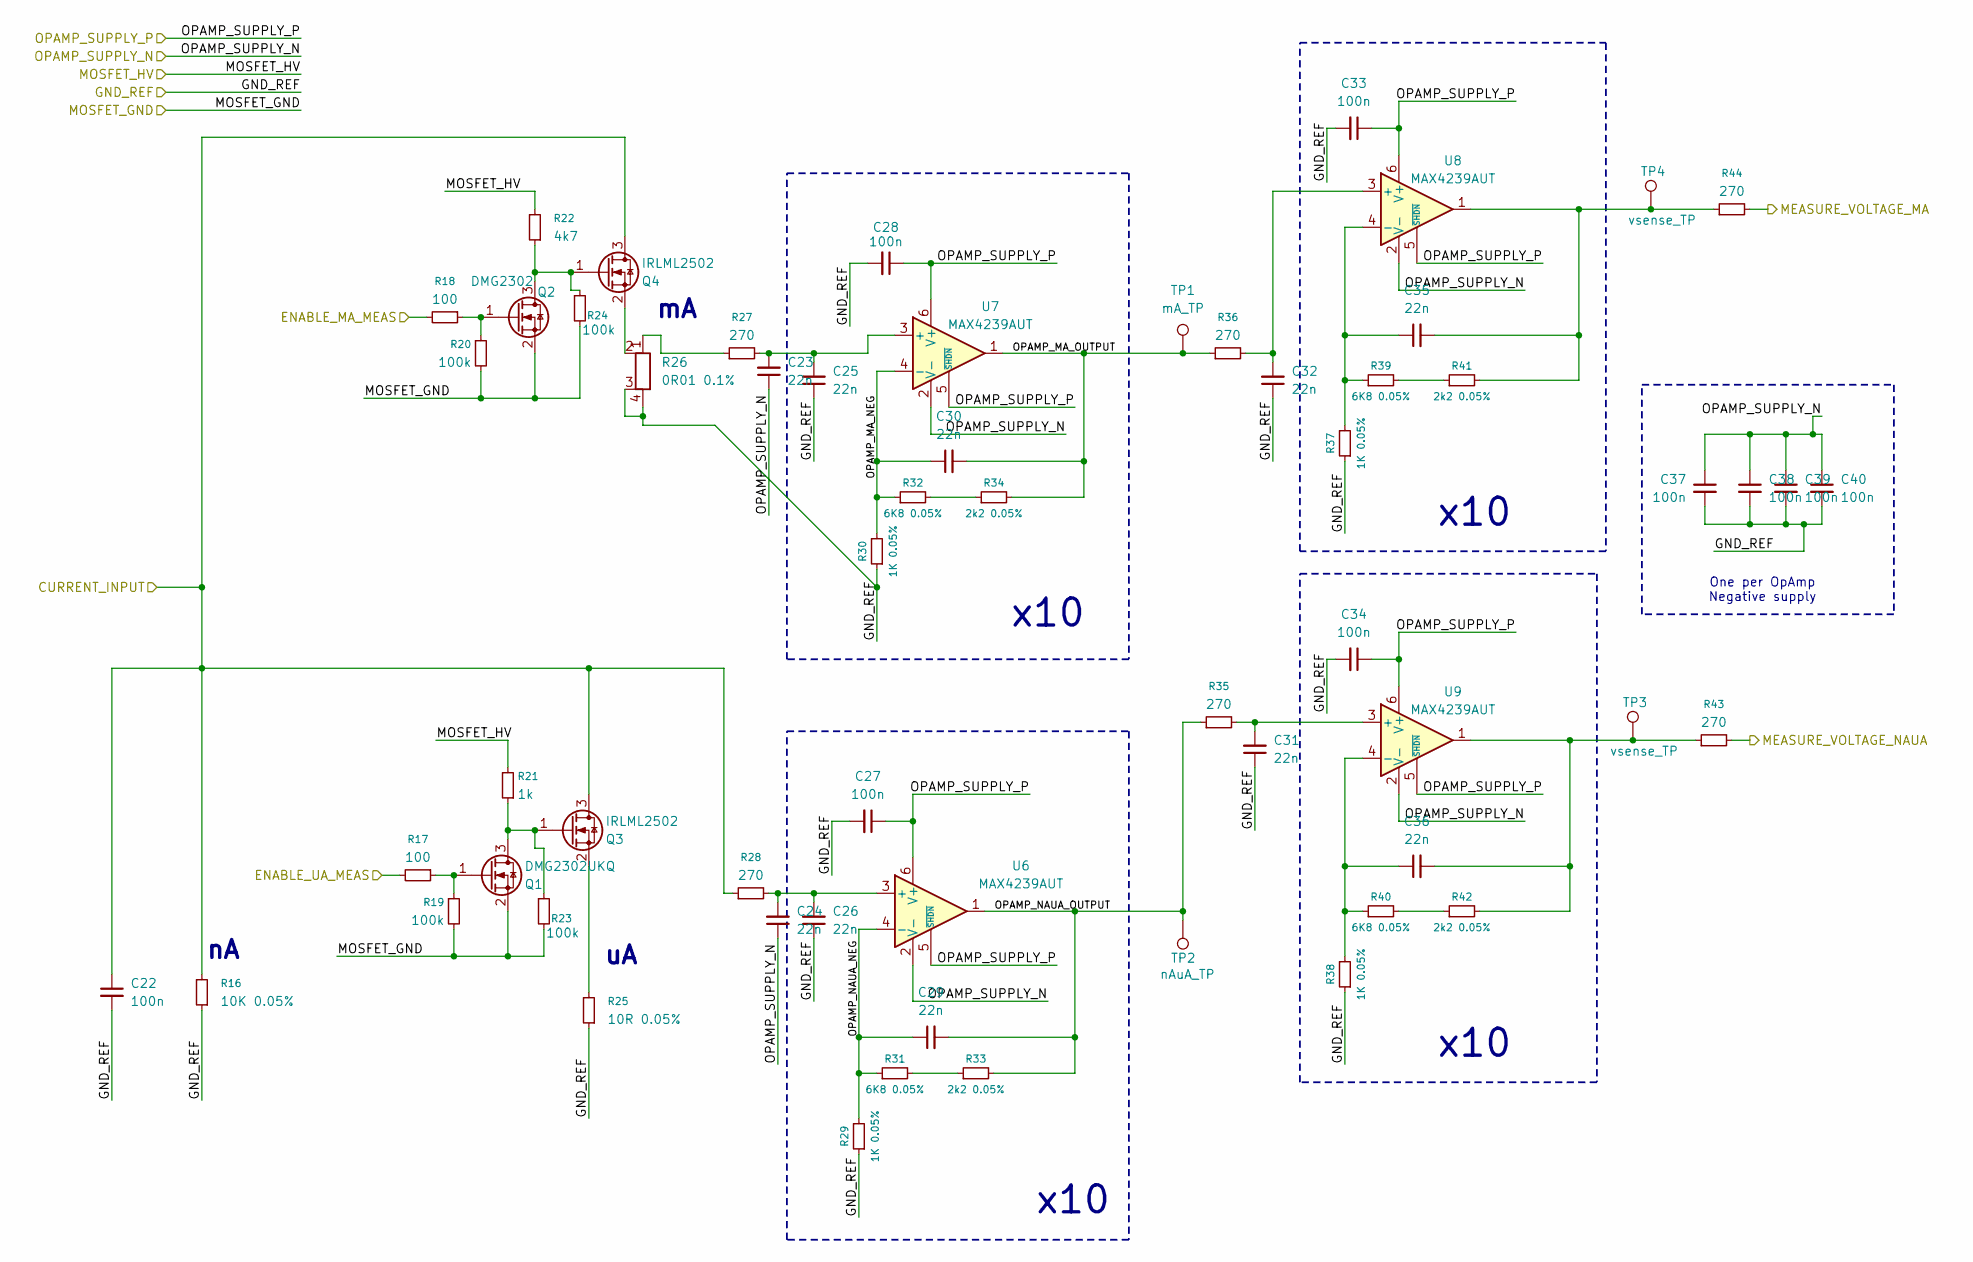
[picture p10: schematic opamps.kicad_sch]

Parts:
C22, C27, C28, C33, C34, C37, C38, C39, C40: 100n; C_0603_1608Metric
C23, C24, C25, C26, C29, C30, C31, C32, C35, C36: 22n; C_0603_1608Metric
Q1: DMG2302UKQ; SOT-23; PartNumber IRLML2502TRPBF
Q2: DMG2302; SOT-23; PartNumber IRLML2502TRPBF
Q3, Q4: IRLML2502; SOT-23; PartNumber IRLML2502TRPBF
R16: 10K 0.05%; R_0603_1608Metric; PartNumber RG1608N-103-W-T5
R17, R18: 100; R_0603_1608Metric
R19, R20, R23, R24: 100k; R_0603_1608Metric
R21: 1k; R_0603_1608Metric
R22: 4k7; R_0603_1608Metric
R25: 10R 0.05%; R_0603_1608Metric; PartNumber RNCF0603AKT10R0
R26: 0R01 0.1%; R_Shunt_Ohmite_LVK12; PartNumber LVK12R010DER
R27, R28, R35, R36, R43, R44: 270; R_0603_1608Metric
R29, R30, R37, R38: 1K 0.05%; R_0603_1608Metric; PartNumber RG1608N-102-W-T5
R31, R32, R39, R40: 6K8 0.05%; R_0603_1608Metric; PartNumber RG1608N-682-W-T1
R33, R34, R41, R42: 2k2 0.05%; R_0603_1608Metric; PartNumber RG1608N-222-W-T1
TP1: mA_TP; TestPoint_Pad_D1.0mm
TP2: nAuA_TP; TestPoint_Pad_D1.0mm
TP3, TP4: vsense_TP; TestPoint_Pad_D1.5mm
U6, U7, U8, U9: MAX4239AUT; SOT-23-6; PartNumber MAX4239AUT+T/OPA189IDBVR

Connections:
/Isolated Supply/5V_ISO: C27.1, C28.1, C33.1, C34.1, U6.5 (~SHDN), U6.6 (V+), U7.5 (~SHDN), U7.6 (V+), U8.5 (~SHDN), U8.6 (V+), U9.5 (~SHDN), U9.6 (V+); also elsewhere on the board
/Isolated/ENABLE_MA: R18.2; also elsewhere on the board
/Isolated/ENABLE_UA: R17.2; also elsewhere on the board
/Isolated/Opamps/CURRENT_INPUT: C22.1, Q3.3 (D), Q4.3 (D), R16.2, R28.1; also elsewhere on the board
/Isolated/Opamps/MEASURE_VOLTAGE_MA: R44.2; also elsewhere on the board
/Isolated/Opamps/MEASURE_VOLTAGE_NAUA: R43.2; also elsewhere on the board
/Isolated/Opamps/MOSFET_HV: R21.2, R22.2; also elsewhere on the board
/Isolated/Opamps/OPAMP_MA_NEG: C30.1, R30.2, R32.1, U7.4 (-)
/Isolated/Opamps/OPAMP_MA_OUTPUT: C30.2, R34.2, R36.1, TP1.1 (1_1), U7.1
/Isolated/Opamps/OPAMP_NAUA_NEG: C29.1, R29.2, R31.1, U6.4 (-)
/Isolated/Opamps/OPAMP_NAUA_OUTPUT: C29.2, R33.2, R35.1, TP2.1 (1_1), U6.1
GNDREF: C22.2, C25.1, C26.1, C27.2, C28.2, C31.1, C32.1, C33.2, C34.2, C37.2, C38.2, C39.2, C40.2, R16.1, R25.1, R26.3, R26.4, R29.1, R30.1, R37.1, R38.1; also elsewhere on the board
GND_ISO: C23.1, C24.1, C37.1, C38.1, C39.1, C40.1, Q1.2 (S), Q2.2 (S), R19.2, R20.2, R23.2, R24.2, U6.2 (V-), U7.2 (V-), U8.2 (V-), U9.2 (V-); also elsewhere on the board
unnamed: C35.2, R41.2, R44.1, TP4.1 (1_1), U8.1
unnamed: C36.2, R42.2, R43.1, TP3.1 (1_1), U9.1
unnamed: Q1.3 (D), Q3.1 (G), R21.1, R23.1
unnamed: Q1.1 (G), R17.1, R19.1
unnamed: Q2.3 (D), Q4.1 (G), R22.1, R24.1
unnamed: Q2.1 (G), R18.1, R20.1
unnamed: Q3.2 (S), R25.2
unnamed: Q4.2 (S), R26.2
unnamed: R26.1, R27.1
unnamed: R31.2, R33.1
unnamed: R32.2, R34.1
unnamed: R39.2, R41.1
unnamed: R40.2, R42.1
unnamed: C24.2, C26.2, R28.2, U6.3 (+)
unnamed: C23.2, C25.2, R27.2, U7.3 (+)
unnamed: C32.2, R36.2, U8.3 (+)
unnamed: C35.1, R37.2, R39.1, U8.4 (-)
unnamed: C31.2, R35.2, U9.3 (+)
unnamed: C36.1, R38.2, R40.1, U9.4 (-)

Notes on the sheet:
x10
One per OpAmp Negative supply

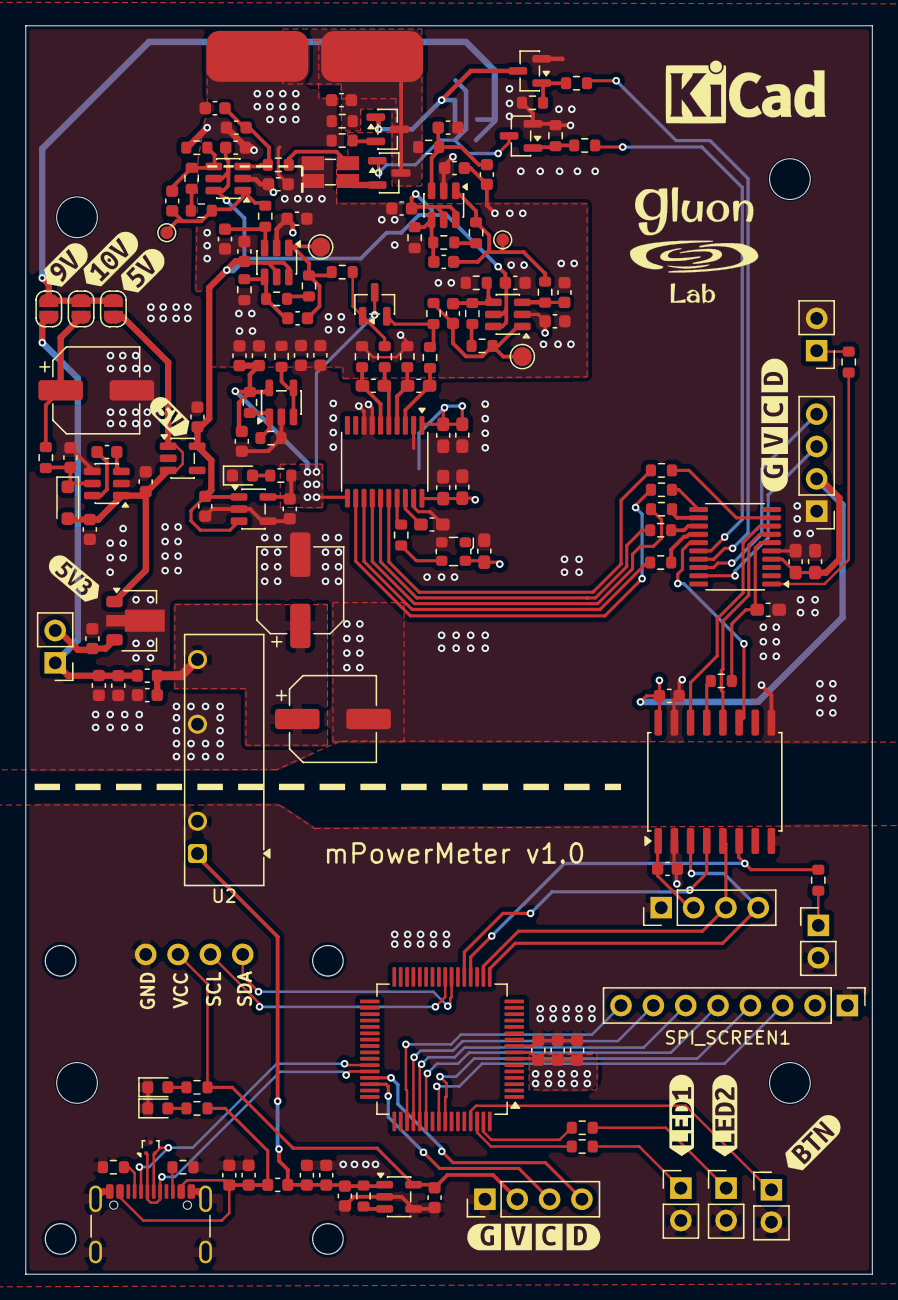
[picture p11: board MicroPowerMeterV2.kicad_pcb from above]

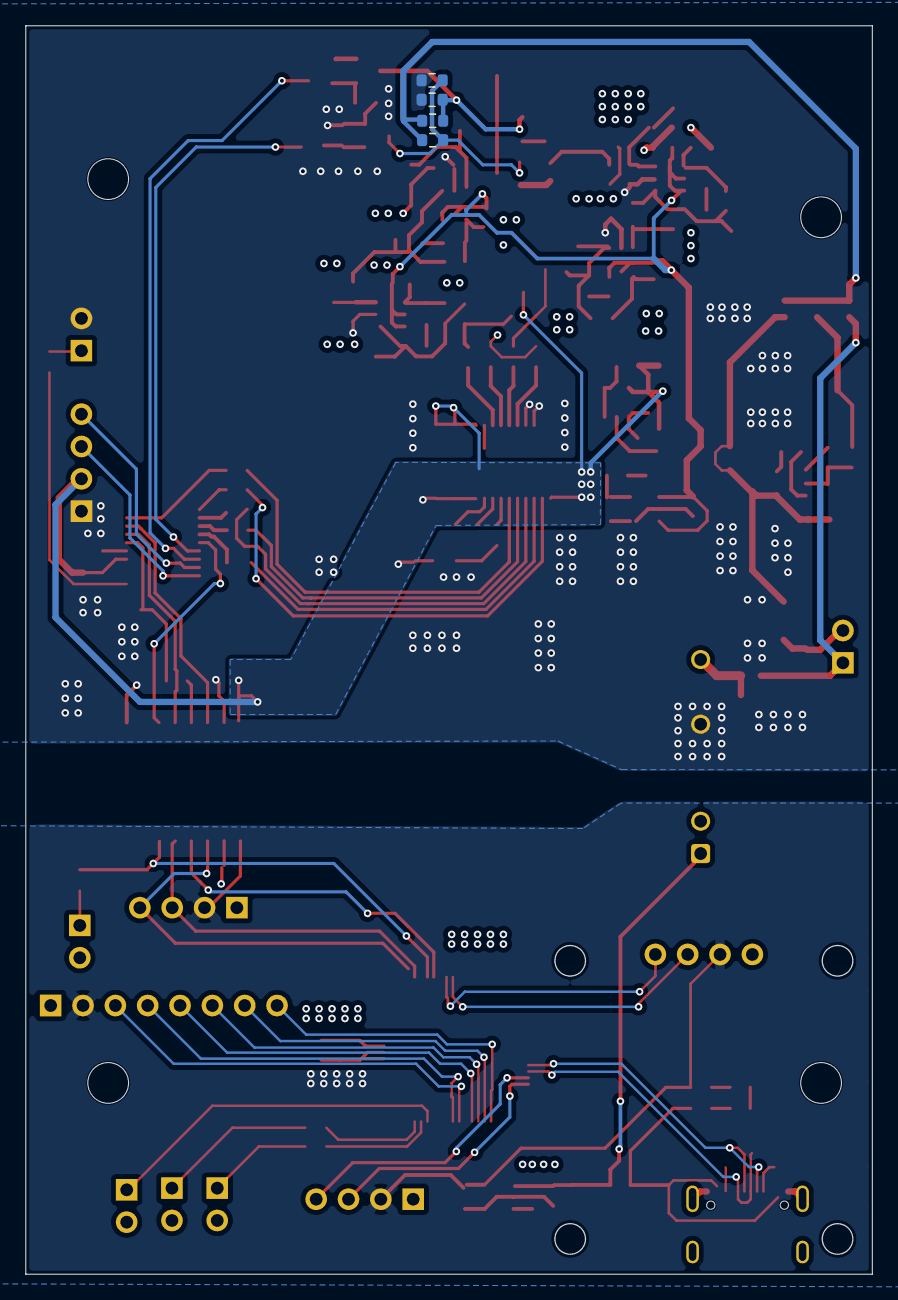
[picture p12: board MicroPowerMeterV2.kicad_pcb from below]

Board: 4 copper layers, 66.5 x 98.1 mm, 173 parts (4 on the bottom side), 101 nets.

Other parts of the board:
kibuzzard-69BFD08A: G***; kibuzzard-69BFD08A
kibuzzard-69BFD09C: G***; kibuzzard-69BFD09C
kibuzzard-69C15ACB: G***; kibuzzard-69C15ACB
kibuzzard-69C15AF6: G***; kibuzzard-69C15AF6
kibuzzard-69C042D6: G***; kibuzzard-69C042D6
kibuzzard-69C1593E: G***; kibuzzard-69C1593E
kibuzzard-69C1596C: G***; kibuzzard-69C1596C
kibuzzard-69C15949: G***; kibuzzard-69C15949
kibuzzard-693C2AD1: G***; kibuzzard-693C2AD1
kibuzzard-698DE9F7: G***; kibuzzard-698DE9F7
